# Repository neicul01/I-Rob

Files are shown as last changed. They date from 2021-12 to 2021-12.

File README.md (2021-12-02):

# I-Rob
Remote Roboter on ESP32 with MQTT
I-Rob
================================
Content of this project is a semi-autonomous robot system for academic teaching. The robot is remotely controlled from the base via the MQTT communication interface. 

Contents
--------

* Installation_
* `Limitations`_
* `Basestation`_
    * `RobotEsp32`_

* `Roboter`_
    * `I-Rob`_
* `Hardeware`_

Installation
------------

1. Install Mosquitto on your PC
2. Customize permission for Mosquitto folders
3. edit the config-file with the following lines

::
	allow_anonymous true
	listeners 1883
Now the Broker is available on Port 1883 and anonymous clients are allowed
4. open the application service and deactivate mosquitto
5. open cmd as admin and navigate to mosquitto folder. The following command is entered there:

::
   mosquitto -v -c mosquitto.conf

The mosquitto-python-library can be installed from here `paho.mqtt.python <https://github.com/eclipse/paho.mqtt.python>'_
More information can be found at `Mosquitto Website <https://mosquitto.org/documentation/authentication-methods/>`_ .
A helpfull tutorial can be found `here <http://www.steves-internet-guide.com/mossquitto-conf-file/>`_ .

Limitations
-----------------

The following feature are unimplemented.

Calibration of the line-sensors.

Basestation
-------------

Detailed API documentation is available through **pydoc**. Samples are available in the **examples** directory.

The package provides two modules, a full client and a helper for simple publishing.

RobotEsp32 userinstruction
**************************

The RobotEsp32 class contains all necessary functions for controlling and reading sensor data.

.. code:: python

    from paho.mqtt import client as mqtt_client
    import RobotEsp32 as classexample

    # The callback for when the client receives a CONNACK response from the server.
    examplebot = classexample.RobotEsp32( your broker IP-Adress, Port (optional if different from port 1883), subscriber-topic, publicher-topic)

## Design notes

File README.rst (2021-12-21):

I-Rob
================================
Content of this project is a semi-autonomous robot system for academic teaching. The robot is remotely controlled from the base via the MQTT communication interface. 

Installation (Windows 10)
----------------------

1. Install Mosquitto-Broker on your PC ( a helpful tutorial can be found `here <http://www.steves-internet-guide.com/install-mosquitto-broker/>`_ ).
2. Customize permission for Mosquitto folders (Depending on the setting, the folder may have limited access rights for the user. These must be changed to full access rights).
3. Edit the config-file with the following lines.

::

	allow_anonymous true
	listeners 1883

Now the Broker is available on Port 1883 and anonymous clients are allowed:

4. Open the application "service" and stop the service "Mosquitto-Broker".
5. Open cmd as admin and navigate to mosquitto folder. The following command is entered there:

::

   mosquitto -v -c mosquitto.conf

The mosquitto-python-library can be installed from `paho.mqtt.python <https://github.com/eclipse/paho.mqtt.python>`_ .
More information can be found at `Mosquitto Website <https://mosquitto.org/documentation/authentication-methods/>`_ .
A helpful tutorial concerning the mossquitto-config-file can be found `here <http://www.steves-internet-guide.com/mossquitto-conf-file/>`_ .

Limitations
-----------------

The following feature are unimplemented:

- Calibration of the line-sensors.

Basestation
-------------

RobotEsp32 user instruction
**************************

The RobotEsp32 class contains all necessary functions for controlling and reading sensor data.

.. code:: python

    from paho.mqtt import client as mqtt_client
    import RobotEsp32 as classexample

'classexample' can be adapted individually.

To initialize a connection the following function is called:

.. code:: python

    examplebot = classexample.RobotEsp32( your broker ip-adress, port (optional if different from port 1883), subscriber-topic, publicher-topic)
Here are two examples for the initialization:  

Example 1 ( default settings are used: Port = 1883, sub_topic="channel_1" and pub_topic="channel_2")

.. code:: python

    examplebot = classexample.RobotEsp32("123.456.789.01")  

Example 2 (individual settings are used: Port= 1883, sub_topic="mytpoic1", pub_topic="mytopic2")

.. code:: python

    examplebot = classexample.RobotEsp32("123.456.789.01", 1883, "mytpoic1", "mytopic2")

Starting the MQTT- Client:    

.. code:: python

    client = examplebot.connect_mqtt()
    client.loop_start()
    
Now all funktions are available,

for example: 

.. code:: python

    examplebot.drive(motor_left, motor_right,client)

Roboter
-------------

The robot software can be uploaded via the Arduino IDE.

1. Installing ESP32 in Arduino IDE (helpful tutorial can be found `here <https://randomnerdtutorials.com/installing-the-esp32-board-in-arduino-ide-windows-instructions/>`_ ).

2. Installing the necessary librarys 
                                      WiFi by Arduino
                                      
                                      PubSubClient by Nick O'Leary
                                      
                                      ESP32Encoder by Kevin Harrington

3. Make sure the roboter is off, than connecting the ESP32 via USB and upload the skretch
4. To make it easier for the user to set the Wi-Fi connection as well as the connection to the Mosquitto broker, a Python script can be used instead of changing the Arduino script.

Wifi-configuration
*******************

0. Make sure the roboter is off!

1. Open the Wifi_configuration script and adapt SSID;Passwort;Broker-ip; in line 17.

2. Adapt COM-Port-number in line 29 and 31 ->if you do not now the port-number than:

	I	Set 'com_port_known' in line 19 to False.
	
	II	Run the script.
	
	III	Connect the ESP32 via USB (ATTENTION: never conect via usb while the roboter is on).
	
	IV	Read the COM-Port-number from output of the script and adapt the COM-Port-number in line 29 and 31.
	
	V	Set 'com_port_known' in line 19 to True.
	
3. Run the script.

4. Connect the ESP32 via USB with the Computer(ATTENTION: never connect via usb while the roboter is on).

5. If the connection to the WLAN and the Broker succeeded, the script will print 'Connection succeeded' -> if not check your SSID, Passwort and Broker-ip in line 17 and your Mqtt-Brokersettings.

6. The Roboter is ready to use.

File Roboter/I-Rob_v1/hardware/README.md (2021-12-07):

External sources
-----------------

Please note that some parts of the Robot.step model come from external sources. These sources are referenced below:

    ESP32 modell https://print.grabcad.com/library/ai-thinker-nodemcu-32s-esp32-development-board-1
    
    Ultrasonic Sensor HC-SR04 https://grabcad.com/library/ultrasonic-sensor-hc-sr04-4/details?folder_id=10273199

Parts list
-----------

| Description | QTY | link  |
| :--- |:---:| :-----|
| Ball Caster| 1 | https://www.robotshop.com/uk/dfrobot-ball-caster-metal-ball.html |
| DIN 912 M1.6x12 | 4 | |
| DIN 912 M3x8 | 10 | |
| DIN 934 M3 | 10 | |
| ELI TR8307 | 2 | https://www.reichelt.de/reflexlichtschranke-0-7mm-submin-4-pol-eli-tr8307-p114341.html |
| ESP32-NodeMCU | 1 | https://www.az-delivery.de/products/esp32-developmentboard?variant=6119648460827 |
| Femal pin header 1x20 | 2 | https://www.aliexpress.com/item/4000386969080.html |
| GW12T-N20VA ratio42 B45 DC6V| 2 | https://de.aliexpress.com/item/1005002458533548.html |
| L293D | 1 | https://de.aliexpress.com/item/1005002121440673.html |
| RCWL-1601 | 2 | https://de.aliexpress.com/item/1005001693758196.html |
| Turnigy Nano-Tech-1000mAh 2s | 1 | https://hobbyking.com/de_de/turnigy-nano-tech-1000mah-2s-25-50c-lipo-pack.html |
| Wheels| 2| https://www.robotshop.com/uk/63mm-wheels-d-shaft-motor-green-2pk.html |

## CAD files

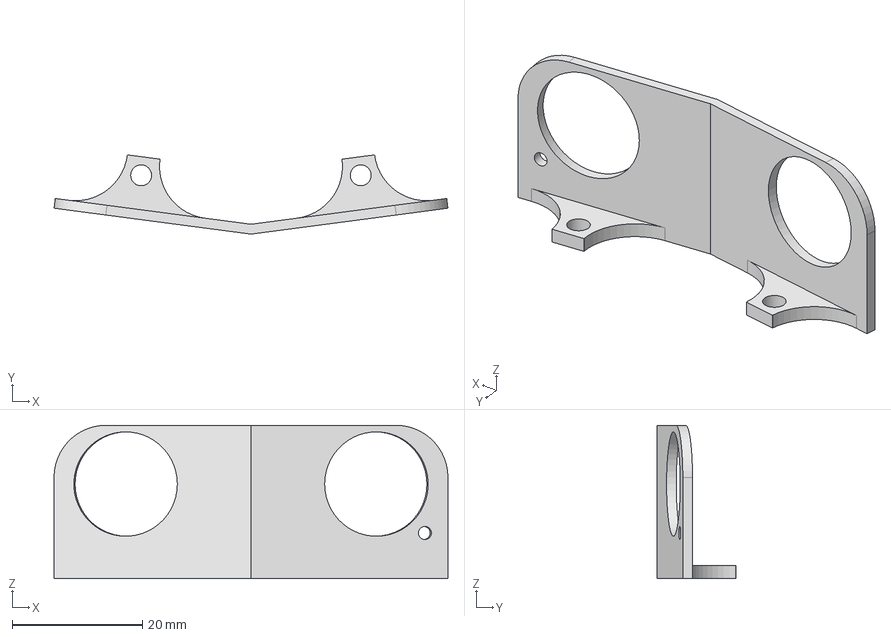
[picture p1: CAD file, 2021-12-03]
Roboter/I-Rob_v1/hardware/sonar_mount.stp
60.4 x 12.1 x 23.5 mm

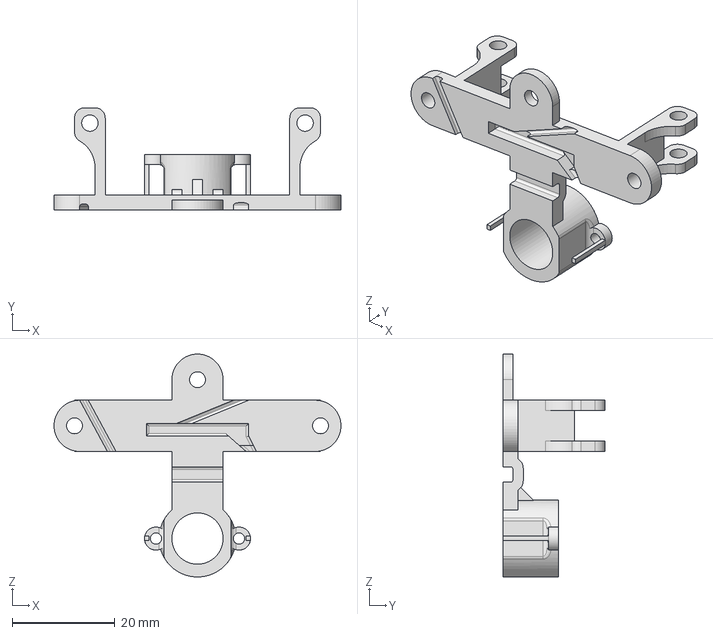
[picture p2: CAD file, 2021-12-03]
Roboter/I-Rob_v1/hardware/Akkucase_T1.stp
56.0 x 20.0 x 43.5 mm

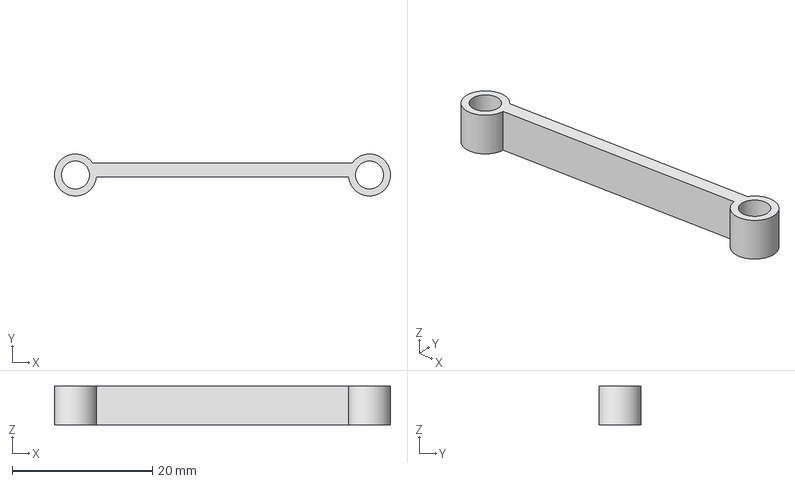
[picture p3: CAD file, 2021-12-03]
Roboter/I-Rob_v1/hardware/Akkucase_T3.stp
48.0 x 6.00 x 5.50 mm

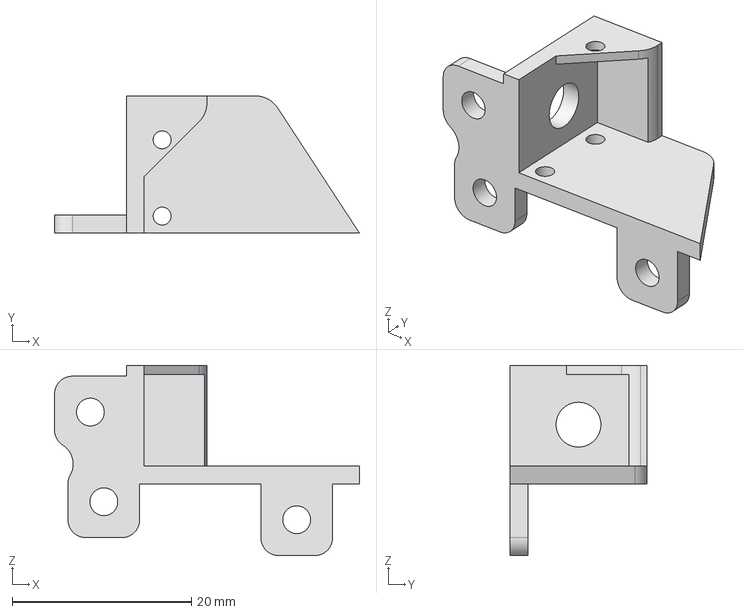
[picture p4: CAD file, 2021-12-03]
Roboter/I-Rob_v1/hardware/motor_mount_left.stp
34.0 x 15.3 x 21.2 mm

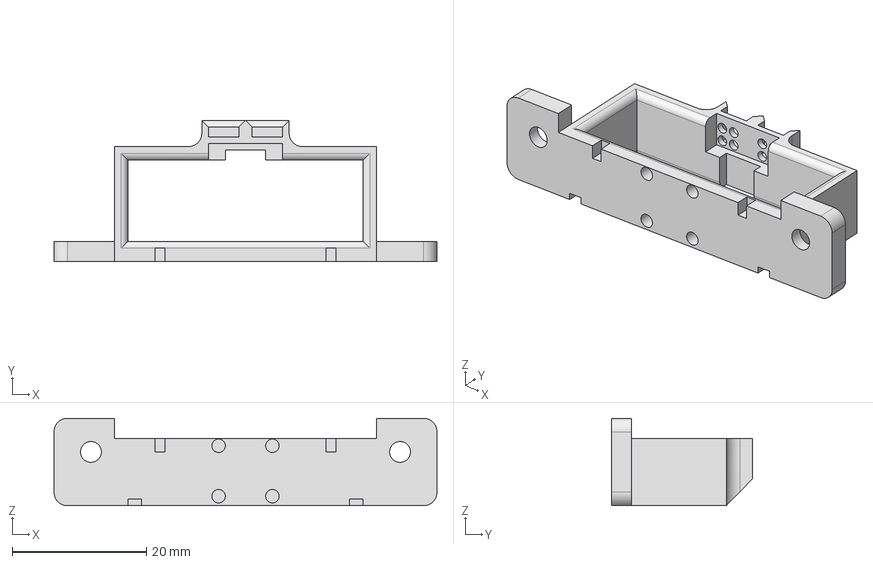
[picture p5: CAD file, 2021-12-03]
Roboter/I-Rob_v1/hardware/Akkucase_T2.stp
57.0 x 21.0 x 13.0 mm

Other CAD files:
Roboter/I-Rob_v1/hardware/motor_mount_right.stp

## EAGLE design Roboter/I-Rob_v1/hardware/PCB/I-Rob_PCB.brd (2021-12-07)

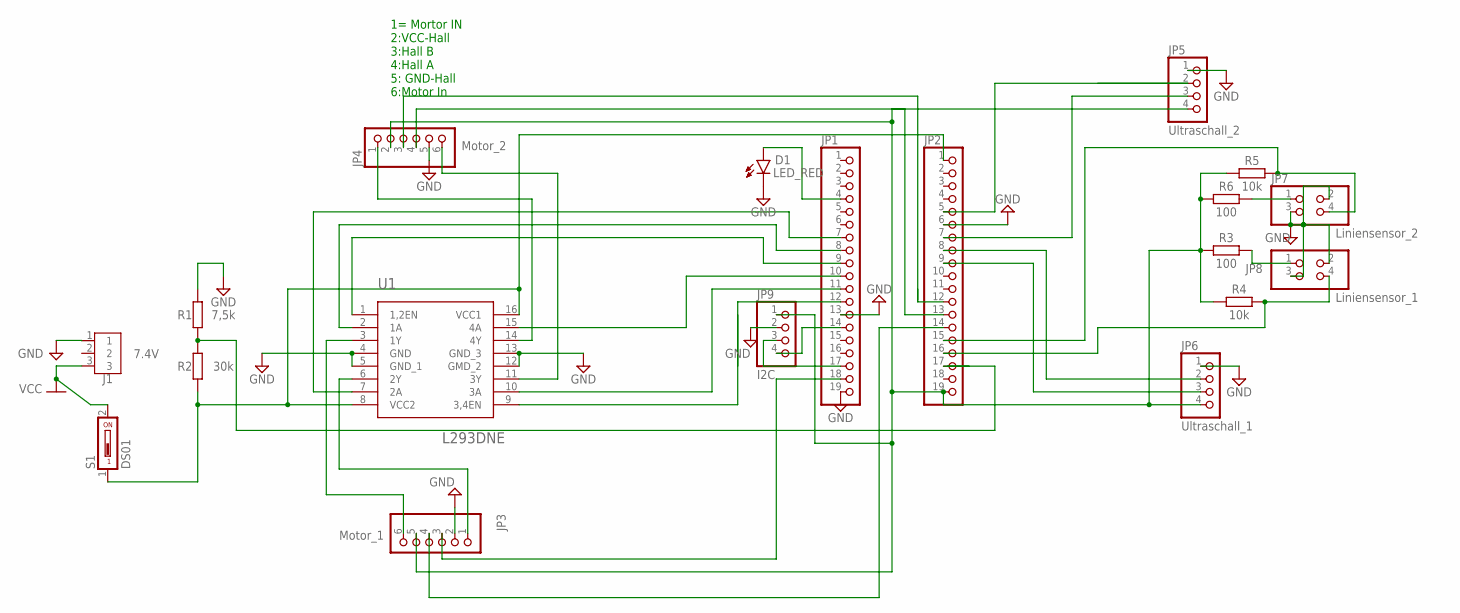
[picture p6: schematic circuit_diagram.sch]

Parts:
D1: LED_RED; LEDRD254W60D565H860B
J1: 7.4V; B3B-XH-A
JP1, JP2: PINHD-1X19; 1X19
JP3: Motor_1; 1X06
JP4: Motor_2; 1X06
JP5: Ultraschall_2; 1X04
JP6: Ultraschall_1; 1X04
JP7: Liniensensor_2; 2X02
JP8: Liniensensor_1; 2X02
JP9: I2C; 1X04
R1: 7,5k; RESAD724W46L381D178B
R2: 30k; RESAD724W46L381D178B
R3, R6: 100; RESAD724W46L381D178B
R4, R5: 10k; RESAD724W46L381D178B
S1: DS01; DS-01
U1: L293DNE; DIP-16_300MIL

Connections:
GND: D1.2 (C), J1.1, JP1.13, JP1.19, JP2.6, JP3.2, JP4.5, JP5.1, JP6.1, JP7.2, JP7.3, JP8.2, JP8.3, JP9.2, R1.2, U1.4 (GND), U1.5 (GND_1), U1.12 (GMD_2), U1.13 (GND_3)
unnamed: JP1.10, U1.15 (4A)
unnamed: JP1.11, U1.10 (3A)
unnamed: JP1.12, U1.9 (3,4EN)
unnamed: JP1.9, U1.1 (1,2EN)
unnamed: JP1.7, U1.7 (2A)
unnamed: JP1.8, U1.2 (1A)
unnamed: JP2.1, R2.1, S1.1, U1.8 (VCC2), U1.16 (VCC1)
unnamed: JP2.17, R1.1, R2.2
unnamed: JP4.6, U1.11 (3Y)
unnamed: JP4.1, U1.14 (4Y)
unnamed: JP3.6, U1.3 (1Y)
unnamed: JP3.1, U1.6 (2Y)
unnamed: JP2.19, JP3.5, JP4.2, JP5.4, JP6.4, JP9.1, R3.1, R4.1, R5.1, R6.1
unnamed: JP8.1, R3.2
unnamed: JP2.5, JP5.2
unnamed: JP7.1, R6.2
unnamed: JP2.15, JP7.4, R5.2
unnamed: JP2.16, JP8.4, R4.2
unnamed: D1.1 (A), JP1.4
unnamed: JP2.7, JP5.3
unnamed: JP2.8, JP6.2
unnamed: JP2.12, JP4.3
unnamed: JP2.9, JP6.3
unnamed: JP2.13, JP4.4
unnamed: JP2.14, JP3.4
unnamed: JP1.18, JP3.3
unnamed: JP1.17, JP9.3
unnamed: JP1.14, JP9.4
VCC: J1.3, S1.2

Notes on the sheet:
1= Mortor IN 2:VCC-Hall 3:Hall B 4:Hall A 5: GND-Hall 6:Motor In

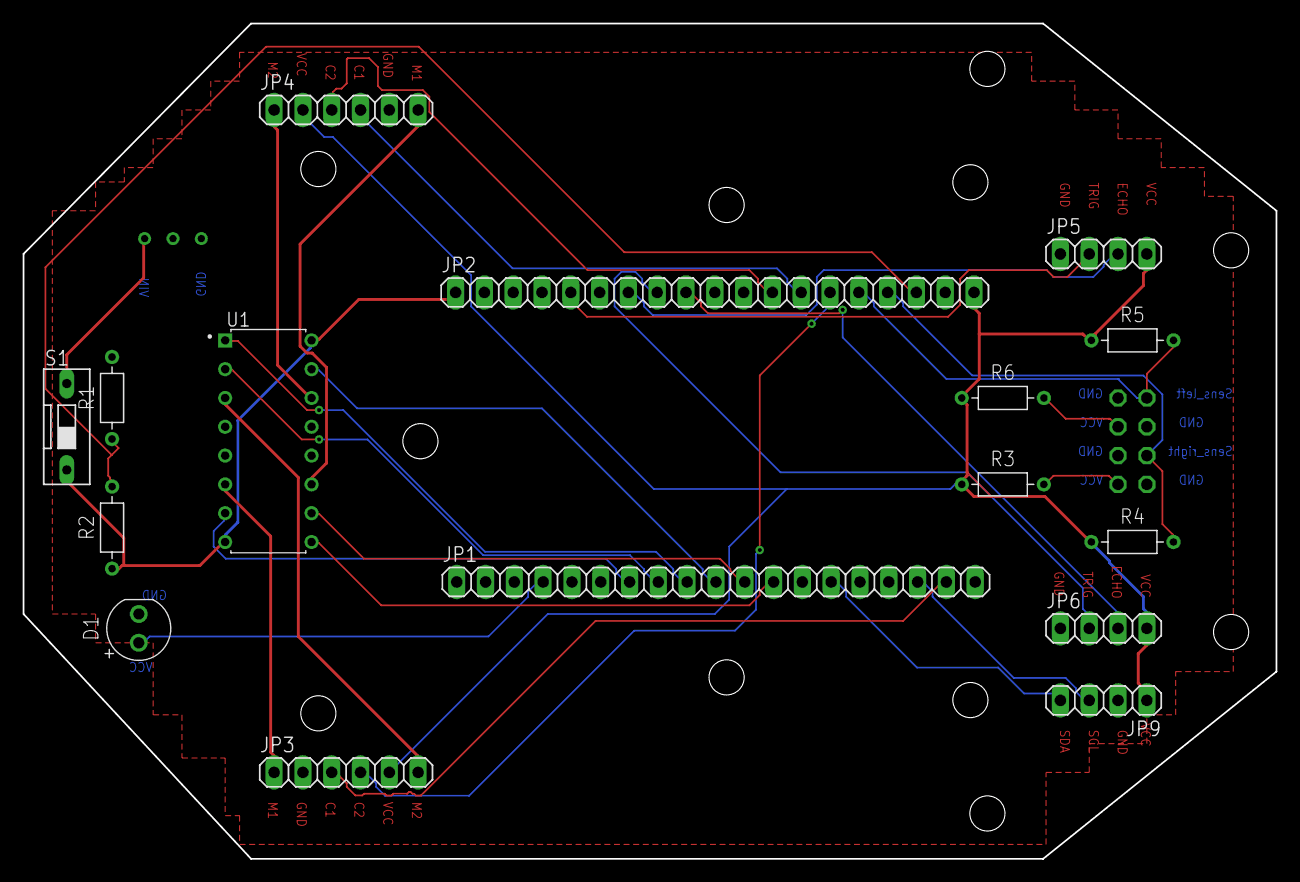
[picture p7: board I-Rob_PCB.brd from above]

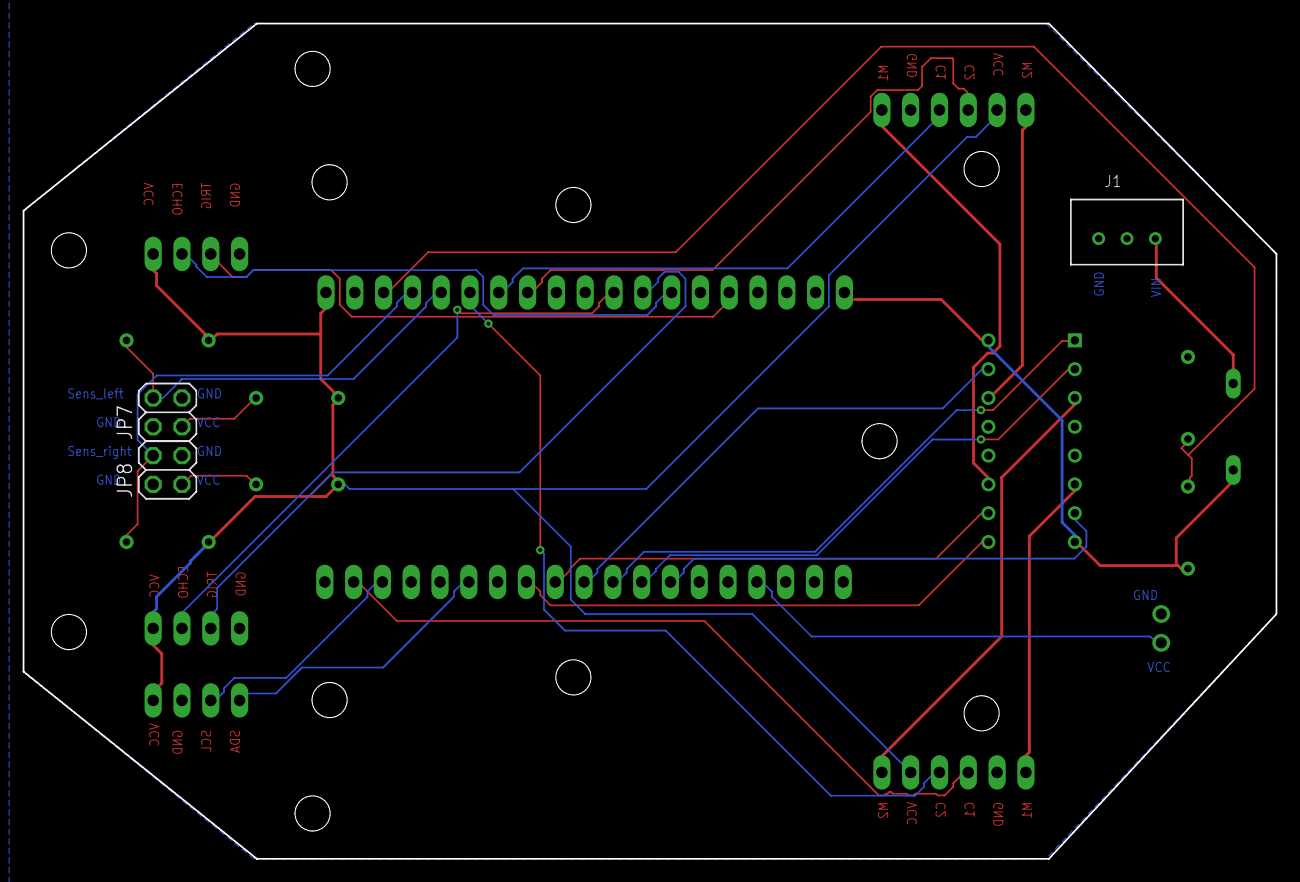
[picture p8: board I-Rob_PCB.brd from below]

Board: 2 copper layers, 110.5 x 73.7 mm, 19 parts (3 on the bottom side), 30 nets.

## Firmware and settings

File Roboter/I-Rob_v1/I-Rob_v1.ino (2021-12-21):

#include <WiFi.h>
#include <PubSubClient.h> //Lib for MQTT Pub and Sub
#include <ESP32Encoder.h>
//


//Hardware Parameter
//ECHO
#define Echo1 14
#define Trig1 27 
#define Echo2 12
#define Trig2 13
//Encoder
#define Enco_A1 23
#define Enco_A2 33
#define Enco_B1 35
#define Enco_B2 32
//Motor
#define motor1Pin1 16
#define motor1Pin2 4
#define enable1Pin 17
#define motor2Pin1 18
#define motor2Pin2 5
#define enable2Pin 19
//Line
#define line_sense_right 39
#define line_sense_left 34
//Akkuvoltage
#define Akku 36

//Wifi configuration
#include <EEPROM.h>
bool newWifi = false;
char inputt[65];
//char* inputt;
char SSID_conf[20];
char PW_conf[25];
char Broker_conf[20];
//EEPROM
int ssid_adress=0;
int pw_adress=100;
int broker_adress=200;
String SSID_conf_str;
String PW_conf_str;
String Broker_conf_str; 

// ultrasonic
int distance_v;
int tof1;
int tof2;
int starttime1;
int line_left;
int line_right;

//Akku
int u_akku = 0;
int pre_u_exp;
int u_exp;
int weight_u = 0.97;
bool u_min=false;

//encoder
ESP32Encoder encoder;
ESP32Encoder encoder2;
// timer and flag for example, not needed for encoders
unsigned long encoder2lastToggled;
unsigned long encoderlastToggled;
unsigned long lastcount_1=0;
unsigned long lastcount_2=0;
unsigned long start_micro=0;
int time_delay=0;
long count2=0;
long count1=0;

//String count2;
unsigned long signal_time=0;
unsigned long last_time=0;
unsigned long sum_time=0;
float freq=0;
float freq_2=0;
int c2;
int c1;
bool c1_neg= false;
bool c2_neg=false;
float freq_filt_1 = 0;
float freq_filt_2 = 0;
float last_freq_filt_1 = 0;
float last_freq_filt_2 = 0;
float weight = 0.9;
float f1;
float f2;

//Ringmemory
float ringsp[101];
float ringsp_2[101];
int pos=0;
int pos_2=0;
float ringsp_sum=0;
float ringsp_sum_2=0;
bool first_sum=true;
bool first_sum_2=true;

int tl=0;
int tr=0;

//PID-controll
int controlmode = 1;   //1 -> motor_right has less power ; 2 -> motor_left has less power; 3 -> both motors have the same power(motor-rotation-difference-controll is off)
float error;
unsigned long PID_loop_time;
unsigned long pre_PID_loop_time[5];
float I_sum[5];
float I_sum_max=1000;//anti_windup
float accel;
float pre_error[5];
float Kp[] = {0.55, 0.55, 0, 0.9,0};     //{motor_right, motor_left, diff_motor_right, diff_motor_left}
float Ki[] = {0.9, 0.9, 0, 0.5,0};
float Kd[] = {0.1, 0.1, 0, 0.1, 0};
int msg_mlef;
int msg_mrig;
//calibration
bool calibrate_PID = false;             // true to manipulate PID-parameter from remote
float P_calib=0.0;
float I_calib=0.0;
float D_calib=0.0;
float P_diff_c=0.0;
bool m_diff = true;                     // true to activate motor-rotation-difference-control
int mleft_d=0;
int mright_d=0;

int len=5;
char buff[10];
char buff1[21];

 
// Setting PWM properties
const int freq_pwm = 30000;
const int pwmChannel = 0;
const int pwmChannel_2 = 1;
const int resolution = 10; //10 Bit motor-geschwindigkeits-auflösung
int deathzone=450; // at 10 Bit the motor isn't running for 0-450
int maxspeed=450; // at 10 Bit 900 is equivalent to 6 Volt. NEVER RUN THE MOTOR OVER 6 VOLT!

//#ifndef STASSID
//#define STASSID "FRITZ!Box 7530"       //Enter Wfi-Name
//#define STAPSK  "12345678912345678910"  //Enter Passkey
//#endif
//const char* MQTT_BROKER = "123.123.123.12";  //Name of the mqtt broker
const char* MQTT_BROKER;
//const char* MQTT_BROKER = "test.mosquitto.org";
const char* PubTopic = "isdtfdw/channel_1";   //Topic where to publish
const char* SUBTOPIC="isdtfdw/channel_2";     //Topic where to subscribe
String clientID = "Roboter";  //Clientname for MQTT-Broker
//
// if the broker is locked with a password, uncommend the following lines
//
//const char* mqttUser = "esp32"; //User
//const char* mqttPassword = "robo"; //Password
WiFiClient espClient;
PubSubClient mqttClient(espClient);

unsigned long lLastMsg = 0;
int iTimeDelay = 2000;  //Set delay for next msg to 2 seconds
#define MSG_BUFFER_SIZE  (50)
char msg[MSG_BUFFER_SIZE];

void setup() 
{
  EEPROM.begin(512);
  Serial.begin(115200); //Start Serial monitor baudrate 115200
  delay(50);
  wifi_config();
  EEPROM.end();
  Serial.println("SerialMonitor enabled");
  setupWifi();
  Serial.println("Set MQTT-Server");
  mqttClient.setServer(MQTT_BROKER,1883);
  Serial.println("Set Callback-function");
  mqttClient.setCallback(callback);
  Serial.println("Finish setup()-Function");
  
  //Encoder setup
  //
  //ESP32Encoder::useInternalWeakPullResistors=DOWN;
  // Enable the weak pull up resistors
  ESP32Encoder::useInternalWeakPullResistors=UP;

  // use pin 19 and 18 for the first encoder
  encoder.attachHalfQuad(Enco_A1, Enco_B1);
  // use pin 17 and 16 for the second encoder
  encoder2.attachHalfQuad(Enco_A2, Enco_B2);
  //encoder2.attachFullQuad(33, 32);
    
  // set starting count value after attaching
  encoder.setCount(37);

  // clear the encoder's raw count and set the tracked count to zero
  encoder2.clearCount();
  encoder.clearCount();
  Serial.println("Encoder Start = " + String((int32_t)encoder.getCount()));
  // set the lastToggle
  encoder2lastToggled = millis();
  encoderlastToggled = millis();

  //Echo
  pinMode(Trig1, OUTPUT);
  pinMode(Echo1, INPUT);
  pinMode(Trig2, OUTPUT);
  pinMode(Echo2, INPUT);
  
  //Motor 
  pinMode(motor1Pin1, OUTPUT);
  pinMode(motor1Pin2, OUTPUT);
  pinMode(enable1Pin, OUTPUT);
  pinMode(motor2Pin1, OUTPUT);
  pinMode(motor2Pin2, OUTPUT);
  pinMode(enable2Pin, OUTPUT);
  // configure LED PWM functionalitites
  ledcSetup(pwmChannel, freq_pwm, resolution);
  ledcSetup(pwmChannel_2, freq_pwm, resolution);
  
  // attach the channel to the GPIO to be controlled
  ledcAttachPin(enable1Pin, pwmChannel);
  ledcAttachPin(enable2Pin, pwmChannel_2);
  
}

void loop() {
  // put your main code here, to run repeatedly:
  if(!mqttClient.connected())
    reconnectMQTT();
  akkustatus();
  rotation();
  distance();
  line();  
  if(f1>7499) f1=7499;                         //to make sure, that f1+2500 is %04d -> (f1+2500) < 10000
  if(f2>7499) f2=7499;
  if(f1<-2500) f1=-2500;                       // to make sure that f1+2500 >= 0, therefore no negative values were transceved
  if(f2<-2500) f2=-2500;
  if(tl>3000) tl=3000;
  if(tr>3000) tr=3000;
  if(tl<-3000) tl=-3000;
  if(tr<-3000) tr=-3000;
  sprintf(buff1,"%04d%04d%04d%04d%04d%04d%04d%04d",((int)f1)+2500,((int)f2)+2500,tr+3000,tl+3000,u_exp,distance_v,line_left,line_right);
  Serial.println(buff1);
  mqttClient.loop();
  mqttClient.publish(PubTopic,buff1,true);    // publish the string buff1 on publisher-topic
  Serial.print(msg_mlef);
  Serial.print(msg_mrig);
  Serial.print(controlmode);
  Serial.print(" ");
  Serial.print(calibrate_PID);
  motorspeed(msg_mlef, msg_mrig);
 
}
/*
* =================================================================
* Function:     callback   
* Returns:      /
* Description:  reads messages from mqtt subscriber-topic
* =================================================================
*/
void callback(char* topic, byte* payload, unsigned int length)
{
  String stMessage = "";
  for (int i = 0; i < length; i++)
    stMessage += String((char)payload[i]);
  msg_mlef = (((int)payload[0]-48)*100+((int)payload[1]-48)*10+payload[2]-48)-450;
  msg_mrig = (((int)payload[3]-48)*100+((int)payload[4]-48)*10+payload[5]-48)-450;
  calibrate_PID=(int)payload[7]-48;
  if(calibrate_PID){
     P_calib = (((int)payload[8]-48)*10+((int)payload[9]-48))/10.0;
     I_calib = (((int)payload[10]-48)*10+((int)payload[11]-48))/10.0;
     D_calib = (((int)payload[12]-48)*100+((int)payload[13]-48)*10+((int)payload[14]-48))/100.0;
    }
  controlmode = (int)payload[6]-48;
  Serial.println("Message is: " + stMessage);
}
/*
* =================================================================
* Function:     akkustatus   
* Returns:      /
* Description:  Check the voltage of the Akku, if the Akku is emty the Motors won't run anymore. This ensures that the battery is not damaged 
* =================================================================
*/
void akkustatus(){
  u_akku=analogRead(Akku);
  u_exp = u_akku * (1 - weight_u) + weight_u * pre_u_exp;
  pre_u_exp = u_exp;
  
  if(u_exp<1475){
    u_min=true;
  }
  
}
/*
* =================================================================
* Function:     motorspeed   
* Returns:      /
* Description:  input: (int mleft, int mright) the motorspeed of each motor, futhermore with the parameter controlmode you can turn on/off the motor-rotation-difference-control: controlmode 1 -> motor_right has less power ; 2 -> motor_left has less power; 3 -> both motors have the same power(motor-rotation-difference-controll is off)
* =================================================================
*/

void motorspeed(int mleft, int mright){
  int mlef;
  int mrig;
 
  if(m_diff){
    mleft = mleft*294/60;   // 294/60 is the factor between frequenz of the encoder and rpm(rotation per minute) of the motor/gear output
    mright = mright*294/60;
    if (controlmode==1){
      if(mright == 0){
        mleft_d=mleft;
      }
      else{
        mleft_d=mleft+PID_control(f2,f1*mleft/mright,3);
      }
      mright_d = mright;
    }
    else if (controlmode == 2){
      if(mleft == 0){
        mright_d = mright;
      }
      else{
        mright_d = mright + PID_control(f1,f2*mright/mleft,3);
      }
    }
    else if (controlmode == 3){
      mright_d = mright;
      mleft_d = mleft;
    }
    
    mlef = PID_control(f2, mleft_d, 1);
    mrig = PID_control(f1, mright_d, 0);
    tl=mlef;
    tr=mrig;
    Serial.print("mlef: ");
    Serial.print(mlef);
    Serial.print(" mrig: ");
    Serial.print(mrig);
  }
  
  else {
    mlef = mleft;
    mrig = mright;
    tl=mlef;
    tr=mrig;
  }
  
  if(mlef>maxspeed){
    mlef=maxspeed;
  }
  else if(mlef<-maxspeed){
    mlef=-maxspeed;
  }
  if(mrig>maxspeed){
    mrig=maxspeed;
  }
  if(mrig<-maxspeed){
    mrig=-maxspeed;
  }
  //to save the Akku, below 3.4V the motors must stop
  if(u_min){
    mlef=0;
    mrig=0;
    
  }
  //motorcontrol
  if(mrig>0){
    mrig=mrig+deathzone;
    digitalWrite(motor1Pin1, LOW);
    digitalWrite(motor1Pin2, HIGH);
    ledcWrite(pwmChannel, mrig); //controll motorspeed with mspeed 450 - 900 
  }
  else if(mrig<0){
    mrig=mrig-deathzone;
    digitalWrite(motor1Pin1, HIGH);
    digitalWrite(motor1Pin2, LOW);
    ledcWrite(pwmChannel, -mrig); //controll motorspeed with mspeed 450 - 900 
  }
  else if(mrig==0){
    digitalWrite(motor1Pin2, HIGH);
    digitalWrite(motor1Pin1, LOW);
    ledcWrite(pwmChannel, 0); //controll motorspeed with mspeed 450 - 900 
  }
  if(mlef>0){
    mlef=mlef+deathzone;
    digitalWrite(motor2Pin2, HIGH);
    digitalWrite(motor2Pin1, LOW);
    ledcWrite(pwmChannel_2, mlef); //controll motorspeed with mspeed 450 - 900 
  }
  else if(mlef<0){
    mlef=mlef-deathzone;
    digitalWrite(motor2Pin2, LOW);
    digitalWrite(motor2Pin1, HIGH);
    ledcWrite(pwmChannel_2, -mlef); //controll motorspeed with mspeed 450 - 900 
  }
  else if(mlef==0){
    digitalWrite(motor2Pin1, HIGH);
    digitalWrite(motor2Pin2, LOW);
    ledcWrite(pwmChannel_2, 0); //controll motorspeed with mspeed 450 - 900 
  }

}

/*
* =================================================================
* Function:     rotation   
* Returns:      /
* Description:  PID-Controller, float value_set is the setpoint value, float value_mes is the measured value (Input), int memory_num is the position in the array of stored values
* =================================================================
*/
void rotation(){
  // Loop and read the count
  count1=(int32_t)encoder.getCount();
  count2=(int32_t)encoder2.getCount();
  c2=count2-lastcount_2;
  c1=count1-lastcount_1;
  signal_time=micros();
  if(c1<0){
    c1_neg=true;
    c1=c1*-1;
  }
  else c1_neg=false;
  if(c2<0){
    c2_neg=true;
    c2=c2*-1;
  }
  else c2_neg=false;
  freq=c1*1000000/(signal_time-last_time);
  freq_2=c2*1000000/(signal_time-last_time);
  float mittelw_1=push(freq,49)/50;
  float mittelw_2=push_2(freq_2,49)/50;
  freq_filt_1=(1-weight)*mittelw_1+weight*last_freq_filt_1;
  freq_filt_2=(1-weight)*mittelw_2+weight*last_freq_filt_2;
  
  //store last values
  last_freq_filt_2=freq_filt_2;
  last_freq_filt_1=freq_filt_1;
  last_time = signal_time;
  lastcount_2 = count2;
  lastcount_1 = count1;

  // Encoder A and B are counting both so /2;
  f1=freq_filt_1/2;
  f2=freq_filt_2/2;
//  Serial.print(" f1: ");
//  Serial.print(freq_filt_1/2);
//  Serial.print(" f2: ");
//  Serial.println(freq_filt_2/2);
}
/*
* =================================================================
* Function:     PID_control   
* Returns:      int
* Description:  PID-Controller, float value_set is the setpoint value, float value_mes is the measured value (Input), int memory_num is the position in the array of stored values
* =================================================================
*/
int PID_control(float value_mes, float value_set, int memory_num){               //memory_num stays for the position in the array of stored "pre_PID_loop" and "I_sum" values
  if(calibrate_PID && memory_num==3){
    Kp[memory_num]=P_calib;
    Ki[memory_num]=I_calib;
  }
  error = value_set - value_mes;                                               //calculate error P-Glied(Geschwindigkeit)
  PID_loop_time = micros() - pre_PID_loop_time[memory_num];                       //Looptime
  accel = (error - pre_error[memory_num]) * 1000000.0 / PID_loop_time;                       //calculate derivative D-Glied(Beschleunigung)
  I_sum[memory_num] = I_sum[memory_num] + (error * (PID_loop_time / 1000000.0)); //calculate integral I-Gleid(Strecke)
  I_sum[memory_num] = max(-I_sum_max, min(I_sum_max, I_sum[memory_num]));       //anti-windup
  int PID_value = Kp[memory_num] * (error + Ki[memory_num] * I_sum[memory_num] + accel * Kd[memory_num]);            //calculate output
  pre_PID_loop_time[memory_num] = micros();                                      //store previous time
  pre_error[memory_num] = error;                                                            //store previous error
  //Serial.print(PID_value);
  //Serial.print(" ");
  return PID_value;
}
/*
* =================================================================
* Function:     push   
* Returns:      float
* Description:  ring puffer witch stores and sum the last x values of fr from type float
* =================================================================
*/
float push(float fr,int x){
  if(c1_neg){
      fr=fr*-1;
    }
  if(first_sum){
    ringsp_sum=ringsp_sum+fr;
  }
  else ringsp_sum=ringsp_sum+fr-ringsp[pos];
  
  ringsp[pos]=fr;
  pos++;
  if(pos>x){
    pos=0;
    first_sum = false;
  }
  return ringsp_sum;
}
float push_2(float fr,int x){
  if(c2_neg){
    fr=fr*-1;
  }
  if(first_sum_2){
    ringsp_sum_2=ringsp_sum_2+fr;
  }
  else ringsp_sum_2=ringsp_sum_2+fr-ringsp_2[pos_2];
  ringsp_2[pos_2]=fr;
  pos_2++;
  if(pos_2>x){
    pos_2=0;
    first_sum_2 = false;
  }
  return ringsp_sum_2;
}
/*
* =================================================================
* Function:     distance   
* Returns:      /
* Description:  get distance values between 0-400 cm
* =================================================================
*/
void distance(){
  digitalWrite(Trig1, HIGH);
  delayMicroseconds(10); 
  digitalWrite(Trig1, LOW);
  tof1 = pulseIn(Echo1, HIGH);
  digitalWrite(Trig2, HIGH);
  delayMicroseconds(10); 
  digitalWrite(Trig2, LOW);
  tof2 = pulseIn(Echo2, HIGH);
  if(tof2<tof1){
    tof1=tof2;
  }
  distance_v=340*tof1/(10000*2);
}
/*
* =================================================================
* Function:     line   
* Returns:      void
* Description:  get Linesensor values between 0-4950 0=max.withe 4950=max.black
* =================================================================
*/
void line(){
  
  line_left = analogRead(line_sense_left);
  line_right = analogRead(line_sense_right);
}
/*
* =================================================================
* Function:     wifi_config   
* Returns:      /
* Description:  reads wifi-config-data from serial Port an store them in EEPROM
* =================================================================
*/
void wifi_config(){
  Serial.println("wifi config");
  delay(1000);
  int i_pos=0;
  while(i_pos<1){
    if (Serial.available() > 0) {
      // read the incoming byte:      inputt = Serial.read();
      while(Serial.available()>0){
        char inchar=Serial.read();
        inputt[i_pos]=inchar;
        i_pos++;
      }
     newWifi= true;
     //inputt=Serial.read();
     // say what you got:
     Serial.print("I r: ");
     Serial.println(inputt);
    }
    else i_pos=1;
  }
  if(newWifi){
    i_pos=0;
    //inputt="FRITZ!Box 7530;12345678912345678910;123.123.123.12;";
    while(inputt[i_pos]!=';'){
      SSID_conf[i_pos]=inputt[i_pos];
      Serial.print(inputt[i_pos]);
      Serial.println( i_pos);
      i_pos++;
    }
    SSID_conf[i_pos]='\0';
    i_pos++;
    int pw_i=0;
    while(inputt[i_pos]!=';'){
      PW_conf[pw_i]=inputt[i_pos];
      Serial.print(inputt[i_pos]);
      Serial.println( i_pos);
      i_pos++;
      pw_i++;
    }
    PW_conf[pw_i]='\0';
    i_pos++;
    int br_i=0;
    while(inputt[i_pos]!=';'){
      Broker_conf[br_i]=inputt[i_pos];
      i_pos++;
      br_i++;
    }
    SSID_conf_str = String(SSID_conf);
    PW_conf_str = String(PW_conf);
    Broker_conf_str = String(Broker_conf); 
    EEPROM.writeString(ssid_adress,SSID_conf_str);
    EEPROM.writeString(pw_adress,PW_conf_str);
    EEPROM.writeString(broker_adress,Broker_conf_str);
    MQTT_BROKER=Broker_conf;
    #ifndef STASSID
    #define STASSID SSID_conf       //Enter Wfi-Name
    #define STAPSK  PW_conf  //Enter Passkey
    #endif
  }

   else {
    SSID_conf_str = EEPROM.readString(ssid_adress);
    PW_conf_str = EEPROM.readString(pw_adress);
    Broker_conf_str = EEPROM.readString(broker_adress);
    SSID_conf_str.toCharArray(SSID_conf,20);
    PW_conf_str.toCharArray(PW_conf,25);
    Broker_conf_str.toCharArray(Broker_conf,20);
    MQTT_BROKER=Broker_conf;
    #ifndef STASSID
    #define STASSID SSID_conf       //Enter Wfi-Name
    #define STAPSK  PW_conf  //Enter Passkey
    #endif
   }
}
void setupWifi()
{
  Serial.println("Connection to: " + String(STASSID));
  WiFi.mode(WIFI_STA);
  WiFi.begin(STASSID, STAPSK);
  while (WiFi.status() != WL_CONNECTED)
  {
    delay(500);
    Serial.print(".");
  }
  Serial.println("");
  Serial.println("WiFi connected");
  Serial.println("IP address: ");
  Serial.println(WiFi.localIP());
}




void reconnectMQTT()
{
  while(!mqttClient.connected())
  {
    Serial.println("Login to MQTT-Broker");
    if(mqttClient.connect(clientID.c_str()))
    {
      Serial.println("Connected to MQTT-Broker " +String(MQTT_BROKER));
      Serial.println("Subscribe topic " + String(SUBTOPIC));
      Serial.println("connection succeeded");
      mqttClient.subscribe(SUBTOPIC,1); //Subscibe topic "SUBTOPIC"
    }
    else
    {
      Serial.println("Failed with rc=" +String(mqttClient.state()));
      Serial.println("Next MQTT-Connect in 3 sec");
      delay(3000);
    }
  }
}

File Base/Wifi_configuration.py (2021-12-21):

# todo's : 0. make sure the roboter is off !
#          1.adapt SSID;Passwort;Broker-ip; in line 17
#          2.adapt COM-Port-number in line 29 and 31 ->if you do not now the port-number than:  I set 'com_port_known' in line 19 to False
#                                                                                               II run the script
#                                                                                               III connect the ESP32 via USB (ATTENTION: never conect via usb while the roboter is on)
#                                                                                               IV read the COM-Port-number from output of the script and adapt the COM-Port-number in line 29 and 31
#                                                                                               V set 'com_port_known' in line 19 to True
#          3.run the script
#          4.connect the ESP32 via USB with the Computer(ATTENTION: never connect via usb while the roboter is on)
#          5.if the connection to the WLAN and the Broker succeeded, the script will print 'Connection succeeded' -> if not check your SSID;Passwort;Broker-ip; in line 17 and your Mqtt-Brokersettings
#          6.the Roboter is ready to use


import time
import serial.tools.list_ports

SSID = 'FRITZ!Box 7530;12345678912345678910;123.456.123.45;'  # 'SSID;Passwort;Broker-ip;'
msg_SSID = bytes(SSID, 'utf-8')
com_port_known = True

while True:
    myport = [tuple(p) for p in list(serial.tools.list_ports.comports())]
    if myport == []:
        print("no devices connected")
    else:
        time.sleep(0.5)
        print(myport)
        if com_port_known:
            esp32_port = [port for port in myport if 'COM4' in port][0]
            if esp32_port in myport:
                ser = serial.Serial(port='COM4',
                                    baudrate=115200,
                                    bytesize=serial.EIGHTBITS,
                                    parity=serial.PARITY_NONE,
                                    timeout=2)

                while True:
                    if ser.isOpen():
                        ser.write(msg_SSID)
                        msg = []
                        msg2 = []
                        i = 0
                        try:
                            while i < 10:
                                # msg.insert(i,ser.read().decode())
                                msg.insert(i, ser.read())
                                i += 1
                            # print(msg)
                            msg2 = [x.decode('utf-8') for x in msg]
                            message = ''.join(map(str, msg2))
                            print(message)
                        except Exception:
                            print("error communicating...: " + str())
                    else:
                        print("cannot open serial port ")

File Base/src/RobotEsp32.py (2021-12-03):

import random
import time
import string
from math import trunc
from paho.mqtt import client as mqtt_client

l_left = 0
l_right = 0
dist = 0
f1 = 0
f2 = 0
motor_stl = 0
motor_str = 0
u_akku = 1600


# Instructions for using the RobotEsp32 class :
#                                               - import RobotEsp32 as classexample
#                                               - examplebot = classexample.RobotEsp32( your broker IP-Adress, Port (optional if different from port 1883), subscriber-topic, publicher-topic)
#                                                   - example1 examplebot = classexample.RobotEsp32("123.456.789.01")  now Port = 1883, sub_topic="channel_1" and pub_topic="channel_2"
#                                                   - example2 examplebot = classexample.RobotEsp32("123.456.789.01", 1883, "mytpoic1", "mytopic2")
#                                               -Starting the MQTT- Client :    client = examplebot.connect_mqtt()
#                                                                               client.loop_start()
#                                               -Calling Function, for example: examplebot.drive(motor_left, motor_right,client)
class RobotEsp32:

    def __init__(self, ip, port=1883, sub_topic='channel_1', pub_topic='channel_2'):
        # self.__broker = 'test.mosquitto.org'
        # self.__broker = '192.168.178.51'
        self.__broker = ip
        # self.__port = 1883
        self.__port = port
        # self.__sub_topic = "isdtfdw/channel_1"
        self.__sub_topic = sub_topic
        # self.__pub_topic = "isdtfdw/channel_2"
        self.__pub_topic = pub_topic

    def connect_mqtt(self):  # -> mqtt_client:
        def on_connect(client, userdata, flags, rc):
            if rc == 0:
                print("Connected to MQTT Broker!")
            else:
                print("Failed to connect, return code %d\n", rc)

        # client.username_pw_set(username, password)
        # generate client ID with pub prefix randomly
        client_id = f'python-mqtt-{random.randint(0, 1000)}'
        client = mqtt_client.Client(client_id)
        client.on_connect = on_connect
        client.connect(self.__broker, self.__port)
        return client

    # function drive(motor left, motor right, mode, calibrate, Kp, Ki, Kd)
    # motor right and left: 0-300 in [rpm]
    # mode: 1-3 (mode = 1 Motor left is stronger; mode = 2 Motor right is stronger; mode = 3 motors have the same torque)
    # calibrate: 1 (the PID-Parameter Kp, Ki,Kd are passed by this function), 0 (the PID-Parameter of the arduino-code are used)
    def drive(self, motor_left, motor_right, client, mode=3, calib=0, p_calib=0, i_calib=0, d_calib=0) -> object:
        msg_count = 0
        if calib > 1:
            calib = 1
        if motor_left > 450:
            motor_left = 450
        elif motor_left < -450:
            motor_left = -450
        if motor_right > 450:
            motor_right = 450
        elif motor_right < -450:
            motor_right = -450
        motor_left_cor = motor_left + 450
        motor_right_cor = motor_right + 450
        ml = list(map(int, str(motor_left_cor)))
        mr = list(map(int, str(motor_right_cor)))
        p = list(map(int, str(p_calib)))
        i = list(map(int, str(i_calib)))
        d = list(map(int, str(d_calib)))
        m_s = list(map(int, str(mode)))
        c_s = list(map(int, str(calib)))
        if motor_left_cor < 10:
            ml.insert(0, 0)
            ml.insert(0, 0)
        elif motor_left_cor < 100:
            ml.insert(0, 0)
        if motor_right_cor < 10:
            mr.insert(0, 0)
            mr.insert(0, 0)
        elif motor_right_cor < 100:
            mr.insert(0, 0)
        if i_calib < 10:
            i.insert(0, 0)
        if p_calib < 10:
            p.insert(0, 0)
        if d_calib < 10:
            d.insert(0, 0)
            d.insert(0, 0)
        if d_calib < 100:
            d.insert(0, 0)
        msg = f"{ml[0]}{ml[1]}{ml[2]}{mr[0]}{mr[1]}{mr[2]}{m_s[0]}{c_s[0]}{p[0]}{p[1]}{i[0]}{i[1]}{d[0]}{d[1]}{d[2]}"
        print(msg)
        result = client.publish(self.__pub_topic, msg)
        status = result[0]

    def get_data(self, client):

        def on_message(client, userdata, msg):
            global f1
            global f2
            global motor_str
            global motor_stl
            # print(f"{msg.payload.decode()}")
            data = msg.payload.decode()
            length = len(data)
            f1 = (int(data[0]) * 1000 + int(data[1]) * 100 + int(data[2]) * 10 + int(data[3])) - 2500
            f2 = (int(data[4]) * 1000 + int(data[5]) * 100 + int(data[6]) * 10 + int(data[7])) - 2500
            motor_stl = (int(data[8]) * 1000 + int(data[9]) * 100 + int(data[10]) * 10 + int(data[11])) - 3000
            motor_str = (int(data[12]) * 1000 + int(data[13]) * 100 + int(data[14]) * 10 + int(data[15])) - 3000
            u_akku = int(data[16]) * 1000 + int(data[17]) * 100 + int(data[18]) * 10 + int(data[19])
            dist = int(data[20]) * 1000 + int(data[21]) * 100 + int(data[22]) * 10 + int(data[23])
            l_left = int(data[24]) * 1000 + int(data[25]) * 100 + int(data[26]) * 10 + int(data[27])
            l_right = int(data[28]) * 1000 + int(data[29]) * 100 + int(data[30]) * 10 + int(data[31])

            if u_akku < 1500:
                print("______battery is empty!!!______")
            # print(f"left: {line_l} right: {line_r} dist: {dist}")
            print(
                f'right: {f1} left: {f2} mo_r: {motor_stl} mo_l: {motor_str} battery:{u_akku} distance:{dist} line_left:{l_left} line_right: {l_right} time: {time.time()}')
            # client.disconnect()

        client.subscribe(self.__sub_topic)
        client.on_message = on_message
        global f1
        global f2
        global motor_str
        global motor_stl
        global l_left
        global l_right
        global dist
        return f1, f2, motor_stl, motor_str, l_left, l_right, dist
